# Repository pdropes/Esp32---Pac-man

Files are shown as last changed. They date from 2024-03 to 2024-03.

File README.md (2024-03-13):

# Esp32_ST7789_Pacman
 Remake of the famous pac-man, with some improvements

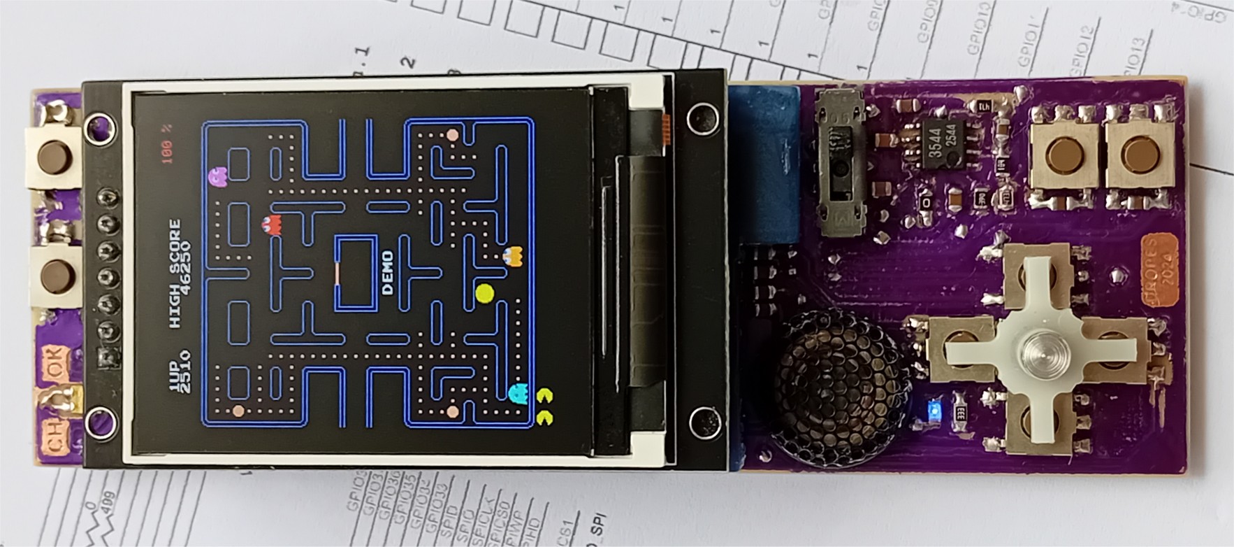
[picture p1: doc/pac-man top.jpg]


!!! NOTICE !!!

## Prepare
- This board was designed to be possible to do at home; the battery is the BL-5B or BL-5C, and the speaker is 32ohms from the 3310.
- In difficulty to find all components, the layout must be changed to support different ones.

## Development Environment
- [Arduino IDE](https://www.arduino.cc/en/main/software)
- [arduino-esp32](https://github.com/espressif/arduino-esp32)

1º Connect the board via USB to the PC.

2º The top buttons are for programming, on the left, IO0, on the right, RESET micro.
For the microcontroller to enter programming mode, the IO0 button must be held down while pressing the reset button briefly.

3º In the Arduino environment, choose "ESP32S2 Dev Module" board.

4º Upload, done.

## Controller
All commands are made on board by switches
LEFT-RIGHT-UP-DOWN , BUTTON A for new game, BUTTON B for pause

## Coding reference
- [Pacman-Arduino-Due](https://github.com/DrNCXCortex/Pacman-Arduino-Due)
- [esp32_ILI9328_Pacman](https://github.com/MhageGH/esp32_ILI9328_Pacman)

Changes:

- Schematic and connections for prototype
- ST7789 support
- Sounds trought two ESP32 8b DAC channels (ambient / effects)
- Functions of buttons A and B
- Show frightened ghosts blinking, before changing to normal
- Battery capacity monitor
- Hiscore saved in internal flash
- Slide-switch to select mode "off/charge" "on/mute" "on/sound"

Revision 1:
- "Battery" font, identical to the rest of the text
- In DEMO mode, the score always remains visible from the last game
- Added missing "Adafruit_BusIO" library

It was my first time programming in C, it may not be perfect.

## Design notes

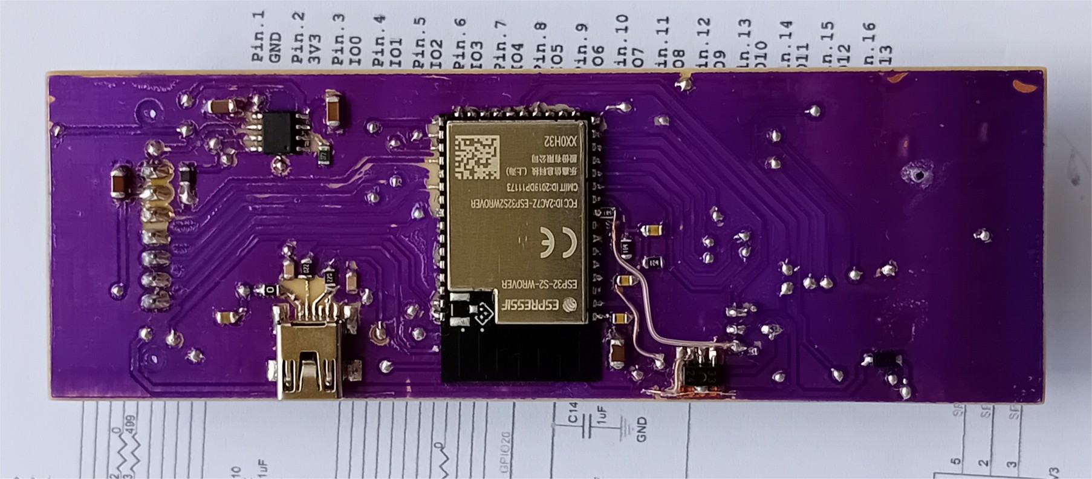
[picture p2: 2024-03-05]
doc/pac-man back.jpg

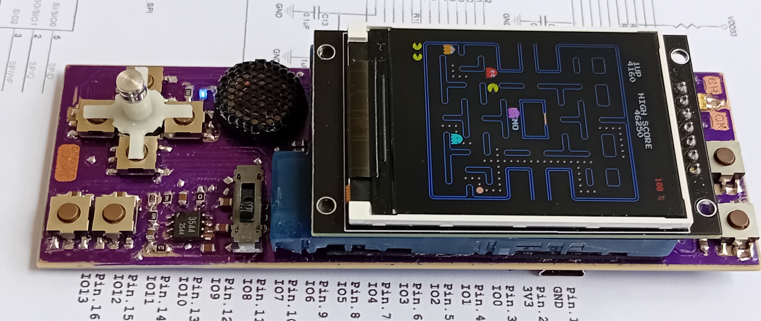
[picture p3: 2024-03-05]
doc/pac-man perspectiva.jpg

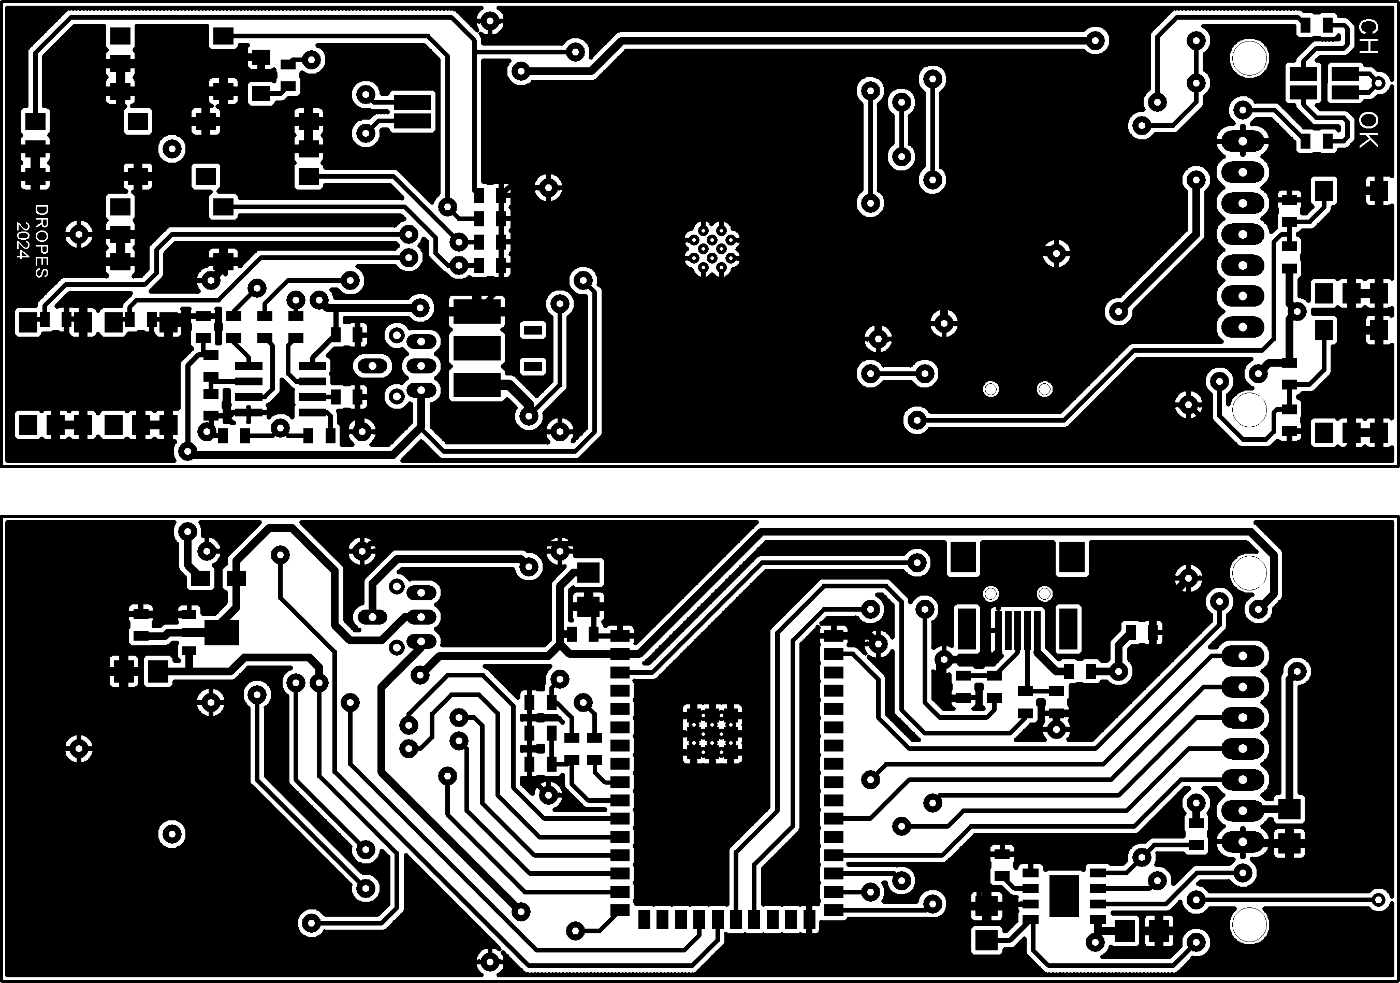
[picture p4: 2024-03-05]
Layout/ESP32-S2_pacman_brd.png

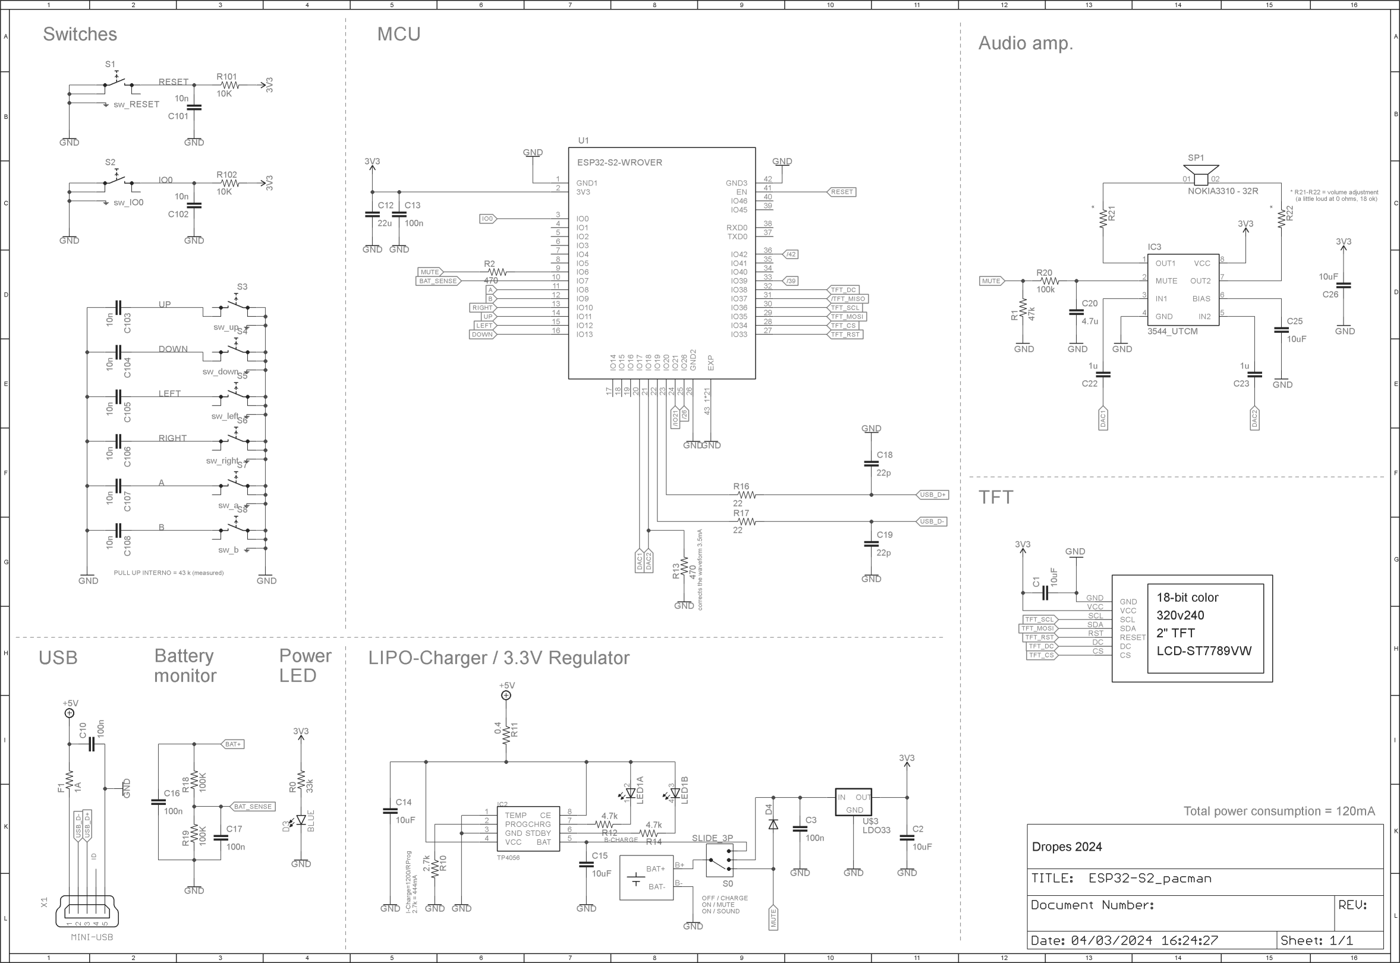
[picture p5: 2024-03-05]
Layout/ESP32-S2_pacman_sch.png

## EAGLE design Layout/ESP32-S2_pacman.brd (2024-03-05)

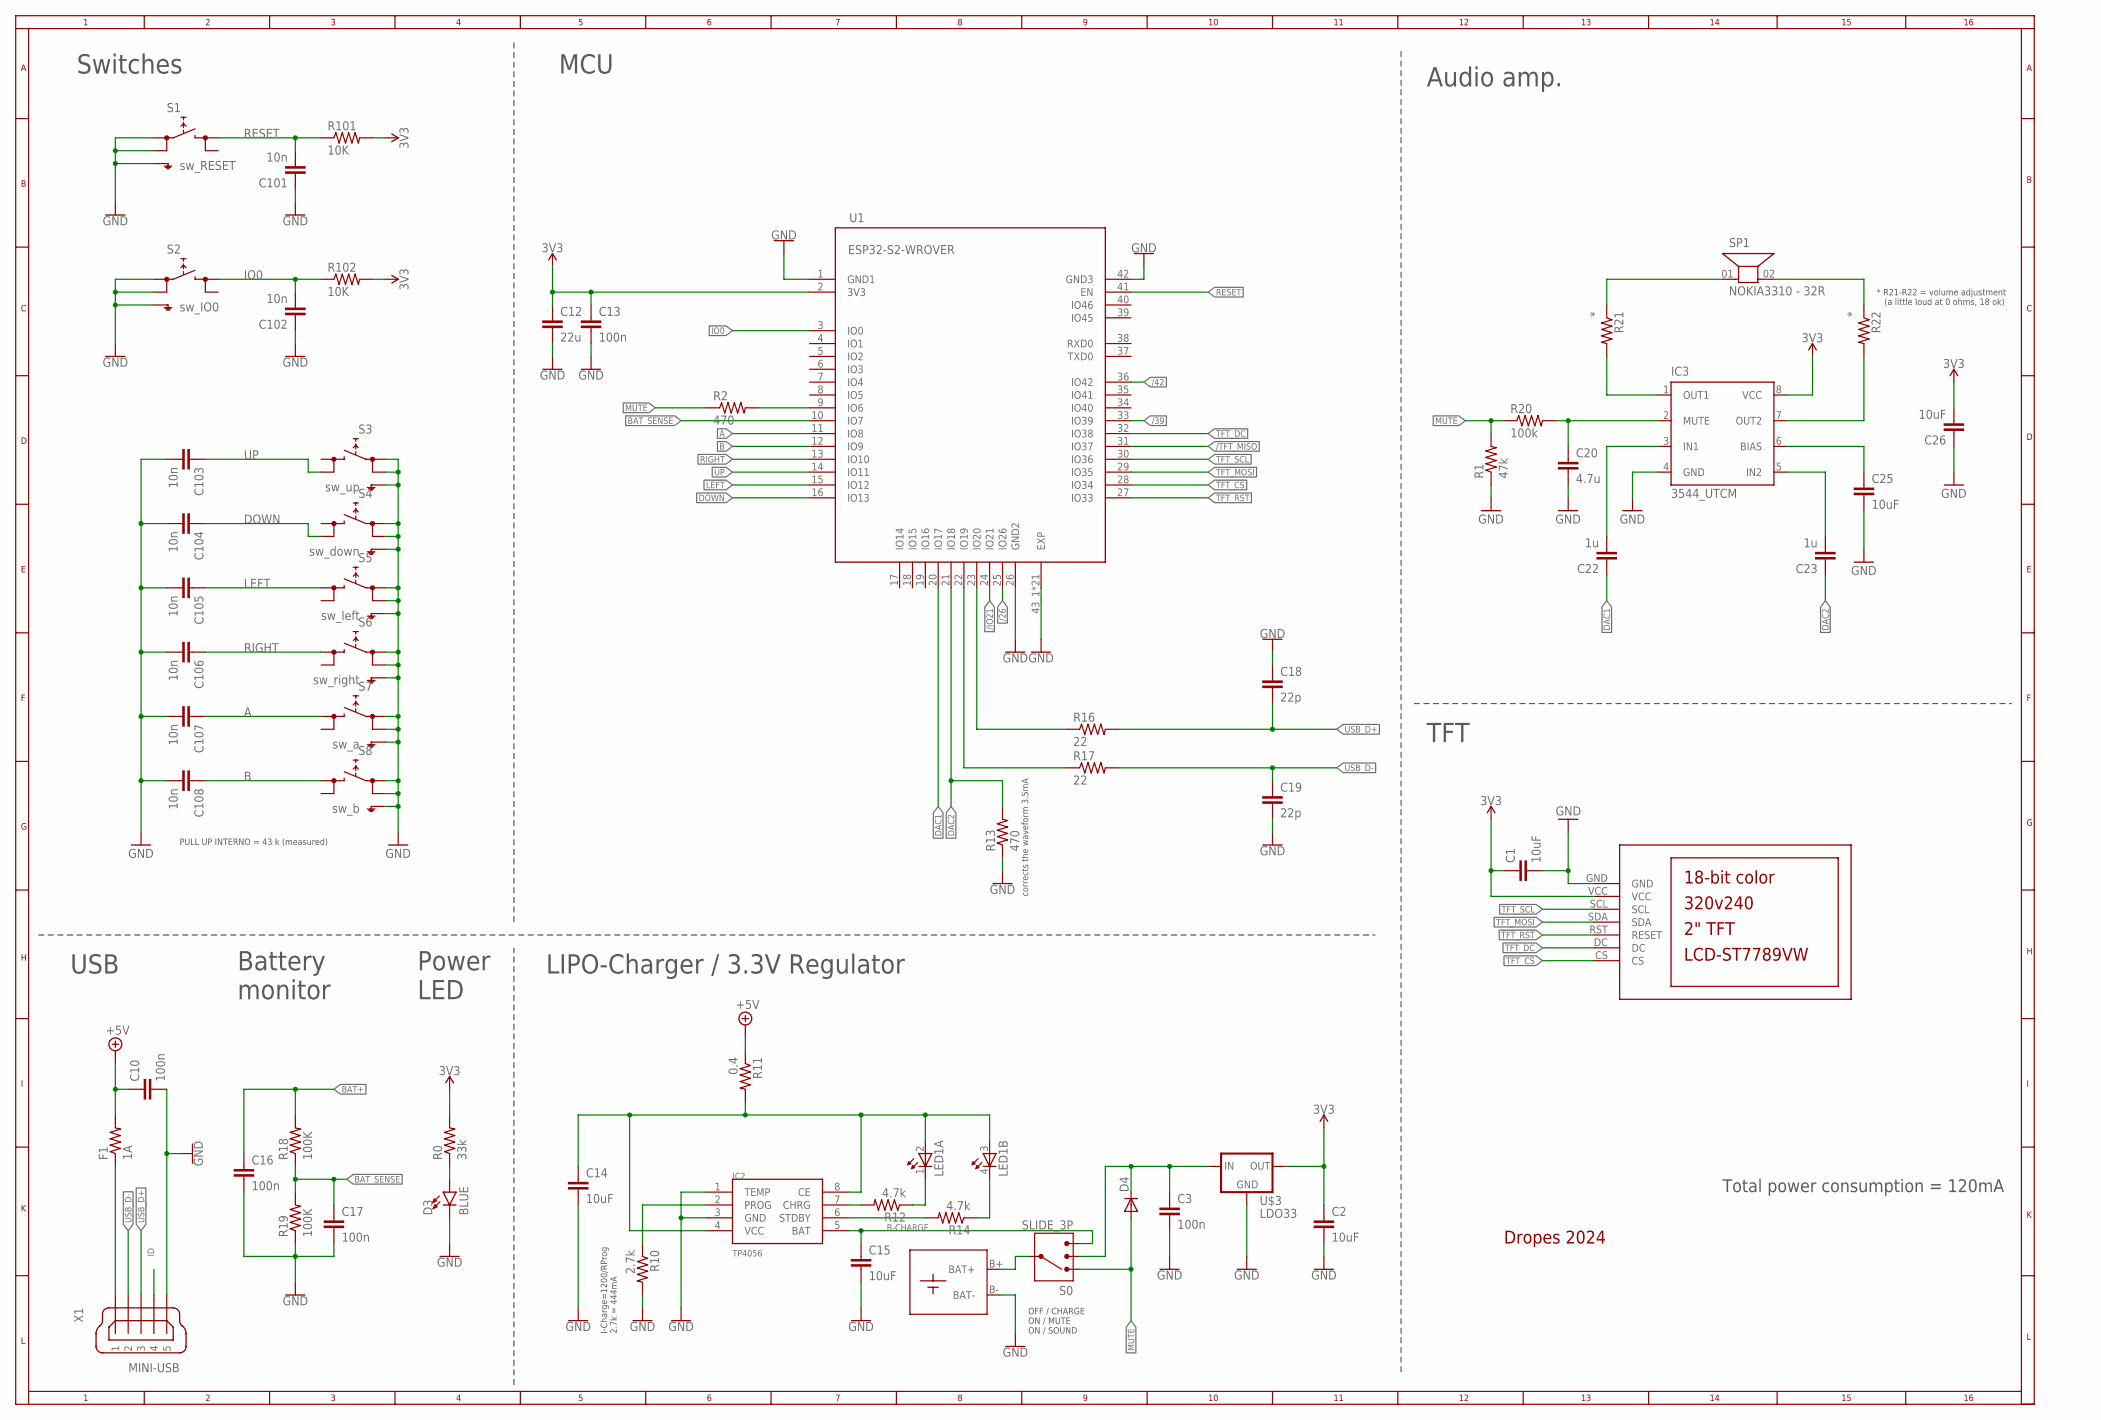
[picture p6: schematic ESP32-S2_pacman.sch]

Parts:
C1, C2, C14, C15: 10uF; 1206
C3, C10, C13, C16, C17: 100n; 0805
C12: 22u; 1206
C18, C19: 22p; 0805
C20: 4.7u; 0805
C22, C23: 1u; 0805
C25, C26: 10uF; 0805
C101, C102, C103, C104, C105, C106, C107, C108: 10n; 0805
D3: BLUE; LED-1206
D4: DIODE-SOD323-W; SOD323-W
F1: 1A; 0805
IC2: TP4056; SOP-8
IC3: 3544_UTCM; SO08
LED1: TOPLED-2--; P-LCC-4-2
R0: 33k; 0805
R1: 47k; 0805
R2, R13: 470; 0805
R10: 2.7k; 0805
R11: 0.4; 0805
R12, R14: 4.7k; 0805
R16, R17: 22; 0805
R18, R19: 100K; 0805
R20: 100k; 0805
R21, R22: *; 0805
R101, R102: 10K; 0805
S0: SLIDE_3P
S1: sw_RESET; SKHMPXE010
S2: sw_IO0; SKHMPXE010
S3: sw_up; SKHMPXE010
S4: sw_down; SKHMPXE010
S5: sw_left; SKHMPXE010
S6: sw_right; SKHMPXE010
S7: sw_a; SKHMPXE010
S8: sw_b; SKHMPXE010
SP1: NOKIA3310 - 32R; AL201P
U1: ESP32-S2-WROVER; MODULE_ESP32-S2-WROVER
U$1: NOKIA_LIPO; BATTERY
U$2: LCD-ST7789VW
U$3: LDO33; SOT89R
X1: MINI-USB; 32005-301

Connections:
+5V: C10.1, F1.2, R11.1
/26: U1.25 (IO26)
/39: U1.33 (IO39)
/42: U1.36 (IO42)
/IO21: U1.24 (IO21)
/TFT_MISO: U1.31 (IO37)
A: C107.1, S7.3 (2.1), U1.11 (IO8)
B: C108.1, S8.3 (2.1), U1.12 (IO9)
B-CHARGE: C15.1, IC2.5 (BAT), S0.P$4 (4)
BAT+: C16.1, R18.2, S0.P$1 (1), U$1.B+ (BAT+)
BAT++: C3.1, D4.C, S0.P$3 (3), U$3.2 (IN), U$3.'2 (IN)
BAT_SENSE: C17.1, R18.1, R19.2, U1.10 (IO7)
DAC1: C22.1, U1.20 (IO17)
DAC2: C23.1, R13.2, U1.21 (IO18)
DOWN: C104.1, S4.4 (2.2), U1.16 (IO13)
GND: C1.2, C2.2, C3.2, C10.2, C12.2, C13.2, C14.2, C15.2, C16.2, C17.2, C18.1, C19.2, C20.2, C25.2, C26.1, C101.1, C102.1, C103.2, C104.2, C105.2, C106.2, C107.2, C108.2, D3.C, IC2.1 (TEMP), IC2.3 (GND), IC3.4 (GND), R1.1, R10.2, R13.1, R19.1, S1.1 (1.1), S1.2 (1.2), S1.5 (SH), S2.1 (1.1), S2.2 (1.2), S2.5 (SH), S3.1 (1.1), S3.2 (1.2), S3.5 (SH), S4.1 (1.1), S4.2 (1.2), S4.5 (SH), S5.1 (1.1), S5.2 (1.2), S5.5 (SH), S6.1 (1.1), S6.2 (1.2), S6.5 (SH), S7.1 (1.1), S7.2 (1.2), S7.5 (SH), S8.1 (1.1), S8.2 (1.2), S8.5 (SH), U1.1 (GND1), U1.26 (GND2), U1.42 (GND3), U1.43_1 (EXP), U1.43_2 (EXP), U1.43_3 (EXP), U1.43_4 (EXP), U1.43_5 (EXP), U1.43_6 (EXP), U1.43_7 (EXP), U1.43_8 (EXP), U1.43_9 (EXP), U1.43_10 (EXP), U1.43_11 (EXP), U1.43_12 (EXP), U1.43_13 (EXP), U1.43_14 (EXP), U1.43_15 (EXP), U1.43_16 (EXP), U1.43_17 (EXP), U1.43_18 (EXP), U1.43_19 (EXP), U1.43_20 (EXP), U1.43_21 (EXP), U$1.B- (BAT-), U$2.GND, U$3.1 (GND), X1.5
ID: X1.4
IN1: C22.2, IC3.3 (IN1)
IO0: C102.2, R102.1, S2.3 (2.1), U1.3 (IO0)
IO52: R16.1, U1.23 (IO20)
IO53: R17.1, U1.22 (IO19)
LEFT: C105.1, S5.3 (2.1), U1.15 (IO12)
MUTE: D4.A, R1.2, R2.1, R20.1, S0.P$2 (2)
unnamed: R21.1, SP1.01 (1)
unnamed: D3.A, R0.1
unnamed: C20.1, IC3.2 (MUTE), R20.2
unnamed: R2.2, U1.9 (IO6)
unnamed: R22.1, SP1.02 (2)
unnamed: IC3.1 (OUT1), R21.2
unnamed: C25.1, IC3.6 (BIAS)
unnamed: IC3.7 (OUT2), R22.2
unnamed: C23.2, IC3.5 (IN2)
unnamed: IC2.2 (PROG), R10.1
unnamed: IC2.7 (CHRG), R12.2
unnamed: IC2.6 (STDBY), R14.2
unnamed: LED1.1 (C), R12.1
unnamed: LED1.4 (C), R14.1
unnamed: C14.1, IC2.4 (VCC), IC2.8 (CE), LED1.2 (A), LED1.3 (A), R11.2
RESET: C101.2, R101.1, S1.3 (2.1), U1.41 (EN)
RIGHT: C106.1, S6.3 (2.1), U1.13 (IO10)
TFT_CS: U1.28 (IO34), U$2.CS
TFT_DC: U1.32 (IO38), U$2.DC
TFT_MOSI: U1.29 (IO35), U$2.SDA
TFT_RST: U1.27 (IO33), U$2.RST (RESET)
TFT_SCL: U1.30 (IO36), U$2.SCL
UP: C103.1, S3.4 (2.2), U1.14 (IO11)
USB+: F1.1, X1.1
USB_D+: C18.2, R16.2, X1.3
USB_D-: C19.1, R17.2, X1.2
VCC: C1.1, C2.1, C12.1, C13.1, C26.2, IC3.8 (VCC), R0.2, R101.2, R102.2, U1.2 (3V3), U$2.VCC, U$3.3 (OUT)

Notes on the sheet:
MCU
USB
TFT
Switches
Audio amp.
corrects the waveform 3.5mA
Total power consumption = 120mA
LIPO-Charger / 3.3V Regulator
I-Charge=1200/RProg 2.7k = 444mA
OFF / CHARGE ON / MUTE ON / SOUND
PULL UP INTERNO = 43 k (measured)
Battery monitor
Power LED
* R21-R22 = volume adjustment (a little loud at 0 ohms, 18 ok)
Dropes 2024

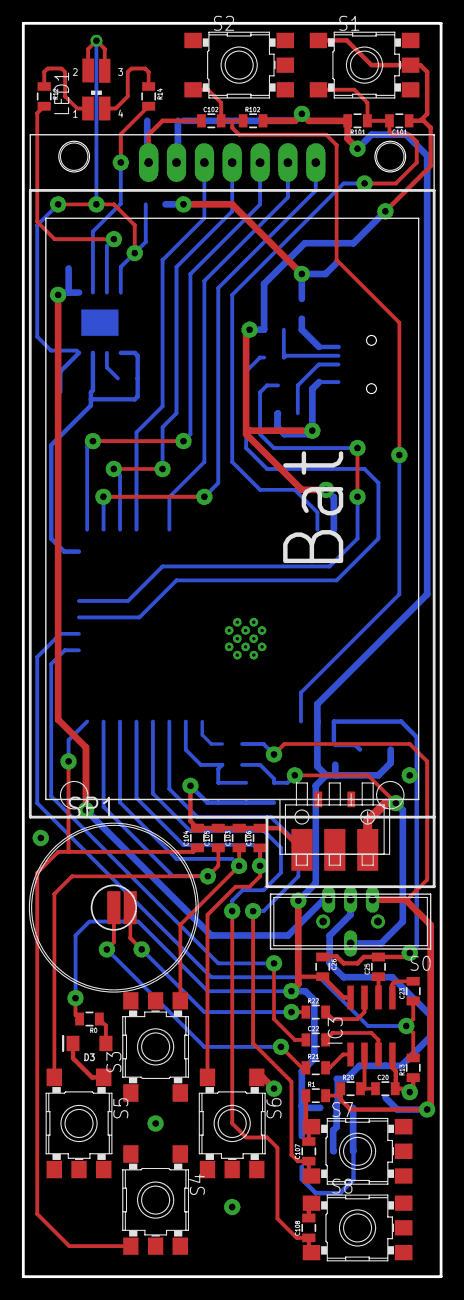
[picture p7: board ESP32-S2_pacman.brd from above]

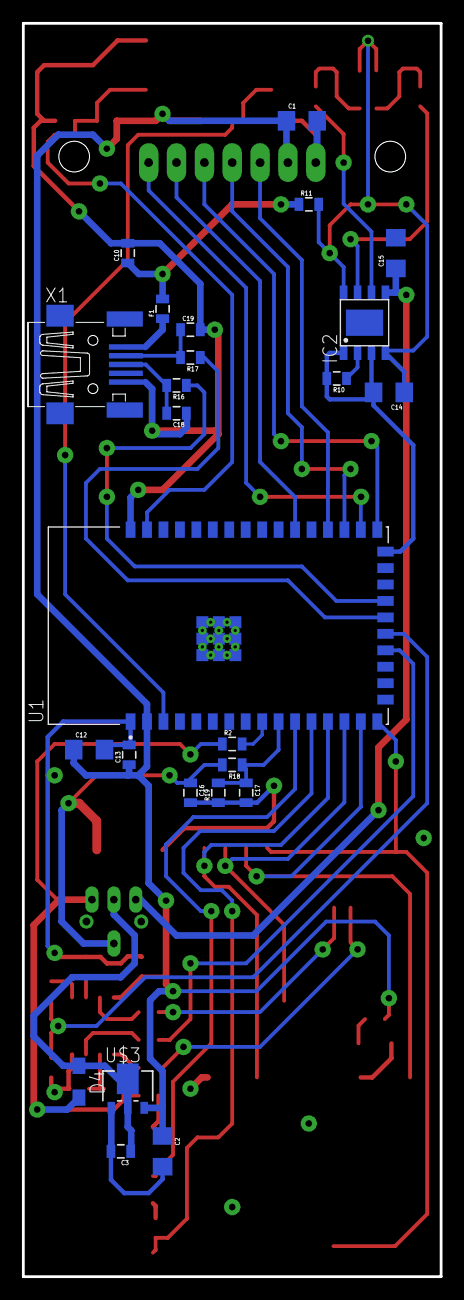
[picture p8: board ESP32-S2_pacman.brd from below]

Board: 2 copper layers, 38.1 x 114.3 mm, 63 parts (25 on the bottom side), 44 nets.

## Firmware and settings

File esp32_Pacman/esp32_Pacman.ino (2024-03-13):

/******************************************************************************/
/*                                                                            */
/*  PACMAN GAME FOR ARDUINO DUE                                               */
/*                                                                            */
/******************************************************************************/
/*  Copyright (c) 2014  Dr. NCX (mirracle.mxx@gmail.com)                      */
/*                                                                            */
/* THE SOFTWARE IS PROVIDED "AS IS" AND THE AUTHOR DISCLAIMS ALL              */
/* WARRANTIES WITH REGARD TO THIS SOFTWARE INCLUDING ALL IMPLIED              */
/* WARRANTIES OF MERCHANTABILITY AND FITNESS. IN NO EVENT SHALL THE AUTHOR    */
/* BE LIABLE FOR ANY SPECIAL, DIRECT, INDIRECT, OR CONSEQUENTIAL DAMAGES      */
/* OR ANY DAMAGES WHATSOEVER RESULTING FROM LOSS OF USE, DATA OR PROFITS,     */
/* WHETHER IN AN ACTION OF CONTRACT, NEGLIGENCE OR OTHER TORTIOUS ACTION,     */
/* ARISING OUT OF OR IN CONNECTION WITH THE USE OR PERFORMANCE OF THIS        */
/* SOFTWARE.                                                                  */
/*                                                                            */
/*  MIT license, all text above must be included in any redistribution.       */

/******************************************************************************/
/*                 ESP32-S2 PAC-MAN     REMASTER BY #DROPES                   */
/******************************************************************************/



byte SPEED = 1; // 1=SLOW 2=NORMAL 4=FAST //do not try  other values!!!

/******************************************************************************/
/*   MAIN GAME VARIABLES                                                      */
/******************************************************************************/

#define BONUS_INACTIVE_TIME 600
#define BONUS_ACTIVE_TIME 300

#define START_LIFES 2
#define START_LEVEL 1

byte MAXLIFES = 5;
byte LIFES = START_LIFES;
byte GAMEWIN = 0;
byte GAMEOVER = 0;
byte DEMO = 1;
byte LEVEL = START_LEVEL;
byte ACTUALBONUS = 0;  //actual bonus icon
byte ACTIVEBONUS = 0;  //status of bonus
byte GAMEPAUSED = 0;

byte PACMANFALLBACK = 0;


#include <Adafruit_GFX.h>    // Core graphics library
#include <Adafruit_ST7789.h> // Hardware-specific library for ST7789
#include <SPI.h>

//LCD_ST7789 :
/*
#define TFT_MOSI 35 
#define TFT_SCLK 36 
*/
#define TFT_CS   34 
#define TFT_DC   38
#define TFT_RST  33
Adafruit_ST7789 tft = Adafruit_ST7789(TFT_CS, TFT_DC, TFT_RST);


#include "DrawindexedMap.h"


// include library to read and write from flash memory
#include <EEPROM.h>

long _hiscore_new;
/******************************************************************************/
/*   SOUND CONFIGURATION                                                    */
/******************************************************************************/  

    #include <driver/dac.h>
    #include "Sounds.h"


    const uint32_t Sample_Size_beginning = sizeof(_beginning) - 1;
    const uint32_t Sample_Size_eatdot = sizeof(_eatdot) - 1;
    const uint32_t Sample_Size_death = sizeof(_death) - 1;
    const uint32_t Sample_Size_eatfruit = sizeof(_eatfruit) - 1;
    const uint32_t Sample_Size_eatghost = sizeof(_eatghost) - 1;
    const uint32_t Sample_Size_extrapac = sizeof(_extrapac) - 1;
    const uint32_t Sample_Size_intermission = sizeof(_intermission) - 1;
    const uint32_t Sample_Size_powerup = sizeof(_powerup) - 1;
    const uint32_t Sample_Size_gethi = sizeof(_gethi) - 1;

    const uint32_t Sample_Size_siren = sizeof(_siren) - 1;        // Sound_loop 1
    const uint32_t Sample_Size_eyeback = sizeof(_eyeback) - 1;    // Sound_loop 2   
                                                                  // Sound_loop 0 = no loop  

    uint32_t Sample_Pos_beginning = Sample_Size_beginning;        //beginning : start new game
    uint32_t Sample_Pos_eatdot = Sample_Size_eatdot;              //eatdot : eat dot
    uint32_t Sample_Pos_death = Sample_Size_death;                //death : pacman die
    uint32_t Sample_Pos_eatfruit = Sample_Size_eatfruit;          //eatfruit : eat fruit
    uint32_t Sample_Pos_eatghost = Sample_Size_eatghost;          //eatghost : eat ghost
    uint32_t Sample_Pos_extrapac = Sample_Size_extrapac;          //extrapac : additional life at 10.000pts
    uint32_t Sample_Pos_intermission = Sample_Size_intermission;  //intermission : new level
    uint32_t Sample_Pos_gethi = Sample_Size_gethi;                //pacman : pac-man enter in hiscore
    uint32_t Sample_Pos_powerup = Sample_Size_powerup;            //powerup : eat big dot
    uint32_t Sample_Pos_siren = Sample_Size_siren;                //normal enviroment
    uint32_t Sample_Pos_eyeback =  Sample_Size_eyeback;           //eyeback : eyes ghost returning to pit

    hw_timer_t *Timer0_Cfg = NULL;
    uint8_t Sound_loop = 0;

    #define SOUND_ON 6
/******************************************************************************/
/*   Battery monitor                                                          */
/******************************************************************************/ 
#define Pin_bat 7 //12bits ADC

/******************************************************************************/
/*   Controll KEYPAD LOOP                                                     */
/******************************************************************************/
#define PIN_A       8
#define PIN_B       9 
#define PIN_UP      11 
#define PIN_DOWN    13 
#define PIN_LEFT    12 
#define PIN_RIGHT   10 

boolean but_A = false;    
boolean but_B = false;   
boolean but_UP = false;  
boolean but_DOWN = false;
boolean but_LEFT = false;
boolean but_RIGHT = false;

/******************************************************************************/
/*   GAME VARIABLES AND DEFINITIONS                                           */
/******************************************************************************/

#include "PacmanTiles.h"

enum GameState {
  ReadyState,
  PlayState,
  DeadGhostState, // Player got a ghost, show score sprite and only move eyes
  DeadPlayerState,
  EndLevelState
};

enum SpriteState
{
  PenState,
  RunState,
  FrightenedState,
  DeadNumberState,
  DeadEyesState,
  AteDotState,    // pacman
  DeadPacmanState
};

enum {
  MStopped = 0,
  MRight = 1,
  MDown = 2,
  MLeft = 3,
  MUp = 4,
};

#define ushort uint16_t

#define BINKY 0
#define PINKY 1
#define INKY  2
#define CLYDE 3
#define PACMAN 4
#define BONUS 5

const byte _initSprites[] =
{
  BINKY,  14,     17 - 3,   31, MLeft,
  PINKY,  14 - 2,   17,     79, MLeft,
  INKY,   14,     17,     137, MLeft,
  CLYDE,  14 + 2,   17,     203, MRight,
  PACMAN, 14,     17 + 9,     0, MLeft,
  BONUS, 14,     17 + 3,     0, MLeft,
};

//  Ghost colors
const byte _palette2[] =
{
  0, 11, 1, 15, // BINKY red
  0, 11, 3, 15, // PINKY pink
  0, 11, 5, 15, // INKY cyan
  0, 11, 7, 15, // CLYDE brown
  0, 11, 9, 9, // PACMAN yellow
  0, 11, 15, 15, // FRIGHTENED
  0, 11, 0, 15, // DEADEYES

  0, 1, 15, 2, // cherry
  0, 1, 15, 12, // strawberry
  0, 7, 2, 12, // peach
  0, 9, 15, 0, // bell

  0, 15, 1, 2, // apple
  0, 12, 15, 5, // grape
  0, 11, 9, 1, // galaxian
  0, 5, 15, 15, // key

};

const byte _paletteIcon2[] =
{
  0, 9, 9, 9, // PACMAN

  0, 2, 15, 1, // cherry
  0, 12, 15, 1, // strawberry
  0, 12, 2, 7, // peach
  0, 0, 15, 9, // bell

  0, 2, 15, 1, // apple
  0, 12, 15, 5, // grape
  0, 1, 9, 11, // galaxian
  0, 5, 15, 15, // key
};

#define PACMANICON 1
#define BONUSICON 2

#define FRIGHTENEDPALETTE 5
#define DEADEYESPALETTE 6

#define BONUSPALETTE 7

#define FPS 60
#define CHASE 0
#define SCATTER 1

#define DOT 7
#define PILL 14
#define PENGATE 0x1B

const byte _opposite[] = { MStopped, MLeft, MUp, MRight, MDown };
#define OppositeDirection(_x) pgm_read_byte(_opposite + _x)

const byte _scatterChase[] = { 7, 20, 7, 20, 5, 20, 5, 0 };
const byte _scatterTargets[] = { 2, 0, 25, 0, 0, 35, 27, 35 }; // inky/clyde scatter targets are backwards
const char _pinkyTargetOffset[] = { 4, 0, 0, 4, -4, 0, -4, 4 }; // Includes pinky target bug

#define FRIGHTENEDGHOSTSPRITE 0
#define GHOSTSPRITE 2
#define NUMBERSPRITE 10
#define PACMANSPRITE 14

const byte _pacLeftAnim[] = { 5, 6, 5, 4 };
const byte _pacRightAnim[] = { 2, 0, 2, 4 };
const byte _pacVAnim[] = { 4, 3, 1, 3 };

word _BonusInactiveTimmer = BONUS_INACTIVE_TIME;
word _BonusActiveTimmer = 0;

u_short _frightenedghostTimer = 0;
/******************************************************************************/
/*   GAME - Sprite Class                                                      */
/******************************************************************************/

class Sprite
{
  public:
    int16_t _x, _y;
    int16_t lastx, lasty;
    byte cx, cy;        // cell x and y
    byte tx, ty;        // target x and y

    SpriteState state;
    byte  pentimer;     // could be the same

    byte who;
    byte _speed;
    byte dir;
    byte phase;

    // Sprite bits
    byte palette2;  // 4->16 color map index
    byte bits;      // index of sprite bits
    signed char sy;

    void Init(const byte* s)
    {
      who = pgm_read_byte(s++);
      cx =  pgm_read_byte(s++);
      cy =  pgm_read_byte(s++);
      pentimer = pgm_read_byte(s++);
      dir = pgm_read_byte(s);
      _x = lastx = (int16_t)cx * 8 - 4;
      _y = lasty = (int16_t)cy * 8;
      state = PenState;
      _speed = 0;
      Target(random(20), random(20));
    }


    void Target(byte x, byte y)
    {
      tx = x;
      ty = y;
    }

    int16_t Distance(byte x, byte y)
    {
      int16_t dx = cx - x;
      int16_t dy = cy - y;
      return dx * dx + dy * dy; // Distance to target
    }

    //  once per sprite, not 9 times
    void SetupDraw(GameState gameState, byte deadGhostIndex)
    {
      sy = 1;
      palette2 = who;
      byte p = phase >> 3;

      if (who == BONUS) {
        //BONUS ICONS
        bits = 21 + ACTUALBONUS;
        palette2 = BONUSPALETTE + ACTUALBONUS;
        return;
      }

      if (who != PACMAN)
      {
        bits = GHOSTSPRITE + ((dir - 1) << 1) + (p & 1); // Ghosts
        switch (state)
        {
          case FrightenedState:
            //60FPS x 10 : frightenedghostTimer = 600
            if (_frightenedghostTimer > 100) {
              bits = FRIGHTENEDGHOSTSPRITE + (p & 1); // frightened
              palette2 = FRIGHTENEDPALETTE;}
            else if (_frightenedghostTimer % 5 != 0) {
              bits = FRIGHTENEDGHOSTSPRITE + (p & 1); // frightened
              palette2 = FRIGHTENEDPALETTE;
            }
            break;
          case DeadNumberState:
            palette2 = FRIGHTENEDPALETTE;
            bits = NUMBERSPRITE + deadGhostIndex;
            break;
          case DeadEyesState:
            palette2 = DEADEYESPALETTE;
            break;
          default:
            ;
        }
        return;
      }

      //  PACMAN animation
      byte f = (phase >> 1) & 3;
      if (dir == MLeft)
        f = pgm_read_byte(_pacLeftAnim + f);
      else if (dir == MRight)
        f = pgm_read_byte(_pacRightAnim + f);
      else
        f = pgm_read_byte(_pacVAnim + f);
      if (dir == MUp)
        sy = -1;
      bits = f + PACMANSPRITE;
    }

    //  Draw this sprite into the tile at x,y
    void Draw8(int16_t x, int16_t y, byte* tile)
    {
      int16_t px = x - (_x - 4);
      if (px <= -8 || px >= 16) return;
      int16_t py = y - (_y - 4);
      if (py <= -8 || py >= 16) return;

      // Clip y
      int16_t lines = py + 8;
      if (lines > 16)
        lines = 16;
      if (py < 0)
      {
        tile -= py * 8;
        py = 0;
      }
      lines -= py;

      //  Clip in X
      byte right = 16 - px;
      if (right > 8)
        right = 8;
      byte left = 0;
      if (px < 0)
      {
        left = -px;
        px = 0;
      }

      //  Get bitmap
      signed char dy = sy;
      if (dy < 0)
        py = 15 - py;  // VFlip
      byte* data = (byte*)(pacman16x16 + bits * 64);
      data += py << 2;
      dy <<= 2;
      data += px >> 2;
      px &= 3;

      const byte* palette = _palette2 + (palette2 << 2);
      while (lines)
      {
        const byte *src = data;
        byte d = pgm_read_byte(src++);
        d >>= px << 1;
        byte sx = 4 - px;
        byte x = left;
        do
        {
          byte p = d & 3;
          if (p)
          {
            p = pgm_read_byte(palette + p);
            if (p)
              tile[x] = p;
          }
          d >>= 2;    // Next pixel
          if (!--sx)
          {
            d = pgm_read_byte(src++);
            sx = 4;
          }
        } while (++x < right);

        tile += 8;
        data += dy;
        lines--;
      }
    }
};

/******************************************************************************/
/*   GAME - Playfield Class                                                   */
/******************************************************************************/

class Playfield
{

    Sprite _sprites[5];

    Sprite _BonusSprite; //Bonus

    byte _dotMap[(32 / 4) * (36 - 6)];

    GameState _state;
    long    _score;             // 7 digits of score
    long    _hiscore;             // 7 digits of score 
    short   _battery;
    long    _lifescore;
    signed char    _scoreStr[8];
    signed char    _hiscoreStr[8];
    signed char    _batteryStr[4];    
    byte           _icons[14];         // Along bottom of screen

    ushort  _stateTimer;
    ushort  _frightenedTimer;
    byte    _frightenedCount;
    byte    _scIndex;           //
    ushort  _scTimer;           // next change of sc status

    bool _inited;
    byte* _dirty;
  public:
    Playfield() : _inited(false)
    {
      //  Swizzle palette TODO just fix in place
//      byte * p = (byte*)_paletteW;
//      for (int16_t i = 0; i < 16; i++)
//      {
//        ushort w = _paletteW[i];    // Swizzle
//        *p++ = w >> 8;
//        *p++ = w;
//      }
    }

    // Draw 2 bit BG into 8 bit icon tiles at bottom
    void DrawBG2(byte cx, byte cy, byte* tile)
    {
      byte index = 0;
      signed char b = 0;

      index = _icons[cx >> 1];   // 13 icons across bottom
      if (index == 0)
      {
        memset(tile, 0, 64);
        return;
      }
      index--;
      index <<= 2;                        // 4 tiles per icon

      b = (1 - (cx & 1)) + ((cy & 1) << 1); // Index of tile

      const byte* bg = pacman8x8x2 + ((b + index) << 4);
      const byte* palette = _paletteIcon2 + index;


      byte x = 16;
      while (x--)
      {
        byte bits = (signed char)pgm_read_byte(bg++);
        byte i = 4;
        while (i--)
        {
          tile[i] = pgm_read_byte(palette + (bits & 3));
          bits >>= 2;
        }
        tile += 4;
      }
    }

    byte GetTile(int16_t cx, int16_t ty)
    {

      if (_state != ReadyState && ty == 20 && cx > 10 && cx < 17) return (0); //READY TEXT ZONE

      if (LEVEL % 5 == 1) return pgm_read_byte(playMap1 + ty * 28 + cx);
      if (LEVEL % 5 == 2) return pgm_read_byte(playMap2 + ty * 28 + cx);
      if (LEVEL % 5 == 3) return pgm_read_byte(playMap3 + ty * 28 + cx);
      if (LEVEL % 5 == 4) return pgm_read_byte(playMap4 + ty * 28 + cx);
      if (LEVEL % 5 == 0) return pgm_read_byte(playMap5 + ty * 28 + cx);
    }

    // Draw 1 bit BG into 8 bit tile
    void DrawBG(byte cx, byte cy, byte* tile)
    {
      if (cy >= 34) //DRAW ICONS BELLOW MAZE
      {
        DrawBG2(cx, cy, tile);
        return;
      }

      byte c = 11;
      if (LEVEL % 8 == 1) c = 11; // Blue
      if (LEVEL % 8 == 2) c = 12; // Green
      if (LEVEL % 8 == 3) c = 1; // Red
      if (LEVEL % 8 == 4) c = 9; // Yellow
      if (LEVEL % 8 == 5) c = 2; // Brown
      if (LEVEL % 8 == 6) c = 5; // Cyan
      if (LEVEL % 8 == 7) c = 3; // Pink
      if (LEVEL % 8 == 0) c = 15; // White

      byte b = GetTile(cx, cy);
      const byte* bg;

      //  This is a little messy
      memset(tile, 0, 64);
      if (cy == 20 && cx >= 11 && cx < 17)
      {
        if (DEMO == 1 && ACTIVEBONUS == 1) return;

        if ((_state != ReadyState && GAMEPAUSED != 1 && DEMO != 1) || ACTIVEBONUS == 1) b = 0; // hide 'READY!'
        else if (DEMO == 1 && cx == 11) b = 0; // hiscore
        else if (DEMO == 1 && cx == 12) b = 'D';
        else if (DEMO == 1 && cx == 13) b = 'E';
        else if (DEMO == 1 && cx == 14) b = 'M';
        else if (DEMO == 1 && cx == 15) b = 'O';
        else if (DEMO == 1 && cx == 16) b = 0;
        else if (GAMEPAUSED == 1 && cx == 11) b = 'P';
        else if (GAMEPAUSED == 1 && cx == 12) b = 'A';
        else if (GAMEPAUSED == 1 && cx == 13) b = 'U';
        else if (GAMEPAUSED == 1 && cx == 14) b = 'S';
        else if (GAMEPAUSED == 1 && cx == 15) b = 'E';
        else if (GAMEPAUSED == 1 && cx == 16) b = 'D';
      }
      else if (cy == 1)
      {
        if (cx < 7)
          b = _scoreStr[cx];
        else if (cx >= 10 && cx < 17)
          b = _hiscoreStr[cx - 10]; // HiScore
        else if (cx >= 23 && cx < 26)
          b = _batteryStr[cx - 23]; // Battery
      } 
      
      
      else {
        if (b == DOT || b == PILL)  // DOT==7 or PILL==16
        {
          if (!GetDot(cx, cy))
            return;
          c = 14;
        }
        if (b == PENGATE)
          c = 14;
      }

      bg = playTiles + (b << 3);
      if (b >= '0')
        c = 15; // text is white

      for (byte y = 0; y < 8; y++)
      {
        signed char bits = (signed char)pgm_read_byte(bg++);  ///WARNING CHAR MUST BE signed !!!
        byte x = 0;
        while (bits)
        {
          if (bits < 0)
            tile[x] = c;
          bits <<= 1;
          x++;
        }
        tile += 8;
      }
    }

    // Draw BG then all sprites in this cell
    void Draw(uint16_t x, uint16_t y, bool sprites)
    {

      byte tile[8 * 8];

      //      Fill with BG
      if (y == 20 && x >= 11 && x < 17 && DEMO == 1 && ACTIVEBONUS == 1)  return;
      DrawBG(x, y, tile);

      //      Overlay sprites
      x <<= 3;
      y <<= 3;
      if (sprites)
      {
        for (byte i = 0; i < 5; i++)
          _sprites[i].Draw8(x, y, tile);

        //AND BONUS
        if (ACTIVEBONUS) _BonusSprite.Draw8(x, y, tile);

      }

      //      Show sprite block
#if 0
      for (byte i = 0; i < 5; i++)
      {
        Sprite* s = _sprites + i;
        if (s->cx == (x >> 3) && s->cy == (y >> 3))
        {
          memset(tile, 0, 8);
          for (byte j = 1; j < 7; j++)
            tile[j * 8] = tile[j * 8 + 7] = 0;
          memset(tile + 56, 0, 8);
        }
      }
#endif

      x += (240 - 224) / 2; // 16/2
      y += (320 - 288) / 2; // 32/2
      
      //      Should be a direct Graphics call

      byte n = tile[0];
      byte i = 0;
      word color = (word)_paletteW[n];

      drawIndexedmap(&tft, tile, x, y);
    }

    boolean updateMap [36][28];

    //  Mark tile as dirty (should not need range checking here)
    void Mark(int16_t x, int16_t y, byte* m)
    {
      x -= 4;
      y -= 4;

      updateMap[(y >> 3)][(x >> 3)] = true;
      updateMap[(y >> 3)][(x >> 3) + 1] = true;
      updateMap[(y >> 3)][(x >> 3) + 2] = true;
      updateMap[(y >> 3) + 1][(x >> 3)] = true;
      updateMap[(y >> 3) + 1][(x >> 3) + 1] = true;
      updateMap[(y >> 3) + 1][(x >> 3) + 2] = true;
      updateMap[(y >> 3) + 2][(x >> 3)] = true;
      updateMap[(y >> 3) + 2][(x >> 3) + 1] = true;
      updateMap[(y >> 3) + 2][(x >> 3) + 2] = true;

    }

    void DrawAllBG()
    {
      for (byte y = 0; y < 36; y++)
        for (byte x = 0; x < 28; x++) {
          Draw(x, y, false);
        }
    }

    //  Draw sprites overlayed on cells
    void DrawAll()
    {
      byte* m = _dirty;

      //  Mark sprite old/new positions as dirty
      for (byte i = 0; i < 5; i++)
      {
        Sprite* s = _sprites + i;
        Mark(s->lastx, s->lasty, m);
        Mark(s->_x, s->_y, m);

      }

      // Mark BONUS sprite old/new positions as dirty
      Sprite* _s = &_BonusSprite;
      Mark(_s->lastx, _s->lasty, m);
      Mark(_s->_x, _s->_y, m);


      //  Animation
      for (byte i = 0; i < 5; i++)
        _sprites[i].SetupDraw(_state, _frightenedCount - 1);

      _BonusSprite.SetupDraw(_state, _frightenedCount - 1);


      for (byte tmpY = 0; tmpY < 36; tmpY++) {
        for (byte tmpX = 0; tmpX < 28; tmpX++) {
          if (updateMap[tmpY][tmpX] == true) Draw(tmpX, tmpY, true);
          updateMap[tmpY][tmpX] = false;
        }

      }
    }
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
void loop() {
  _game.Step();
  KeyPadLoop();
}

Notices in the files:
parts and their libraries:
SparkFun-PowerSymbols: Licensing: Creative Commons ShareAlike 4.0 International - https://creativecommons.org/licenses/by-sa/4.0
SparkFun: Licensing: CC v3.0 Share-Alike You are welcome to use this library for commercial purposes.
